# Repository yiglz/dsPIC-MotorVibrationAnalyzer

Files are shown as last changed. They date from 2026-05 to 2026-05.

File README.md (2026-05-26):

# dsPIC-MotorVibrationAnalyzer
Complete hardware and bare-metal firmware for real-time industrial motor vibration diagnostics using the dsPIC33F DSP engine.

Industrial motors vibrate in specific ways before they break down. This project acts as an early warning system. It is a custom-built embedded device that listens to motor vibrations, mathematically analyzes the frequencies in real-time, and points out mechanical issues before a failure happens.

Vibration_dsPIC33

**Used ICs:** dsPIC33FJ64MC204 (MCU), ADXL335 (Analog Accelerometer), MAX3232 (UART-RS232 Bridge), NCP716 & TLF50241ELV50 (Voltage Regulators).

This project does not use an operating system or HAL libraries. It is entirely written in bare-metal C.

To save energy, the system defaults to a deep hardware sleep mode. The operational workflow is executed as follows:

1. The user presses the physical **START BUTTON**. The processor wakes up and activates the status LED.
2. 10-second timer is started. During this time, ADC captures 4,000 samples of the vibration every single second.
3. To move data, DMA controller is used. The DMA continuously streams incoming data into a primary memory.
4. Once the first memory array is full, the DMA redirects data to a secondary array (Ping-Pong buffering). While the secondary array fills, the main processor executes FFT on the first one. Working in parallel ensures the system never misses a sample.
5. After 10 seconds, the device stops sampling. It averages the magnitudes and transmits a list of frequencies to a terminal via the RS232 port before returning to sleep.

This repository contains:
* **Firmware (`.c` & `.h` files):** Full bare-metal C source code, including register-level configurations for DMA, dual-channel ADC, Timers, UART, and the Complex FFT algorithms.
* **Schematic PDF:** The complete circuit diagram.
* **Gerber Files:** Production-ready PCB manufacturing files.

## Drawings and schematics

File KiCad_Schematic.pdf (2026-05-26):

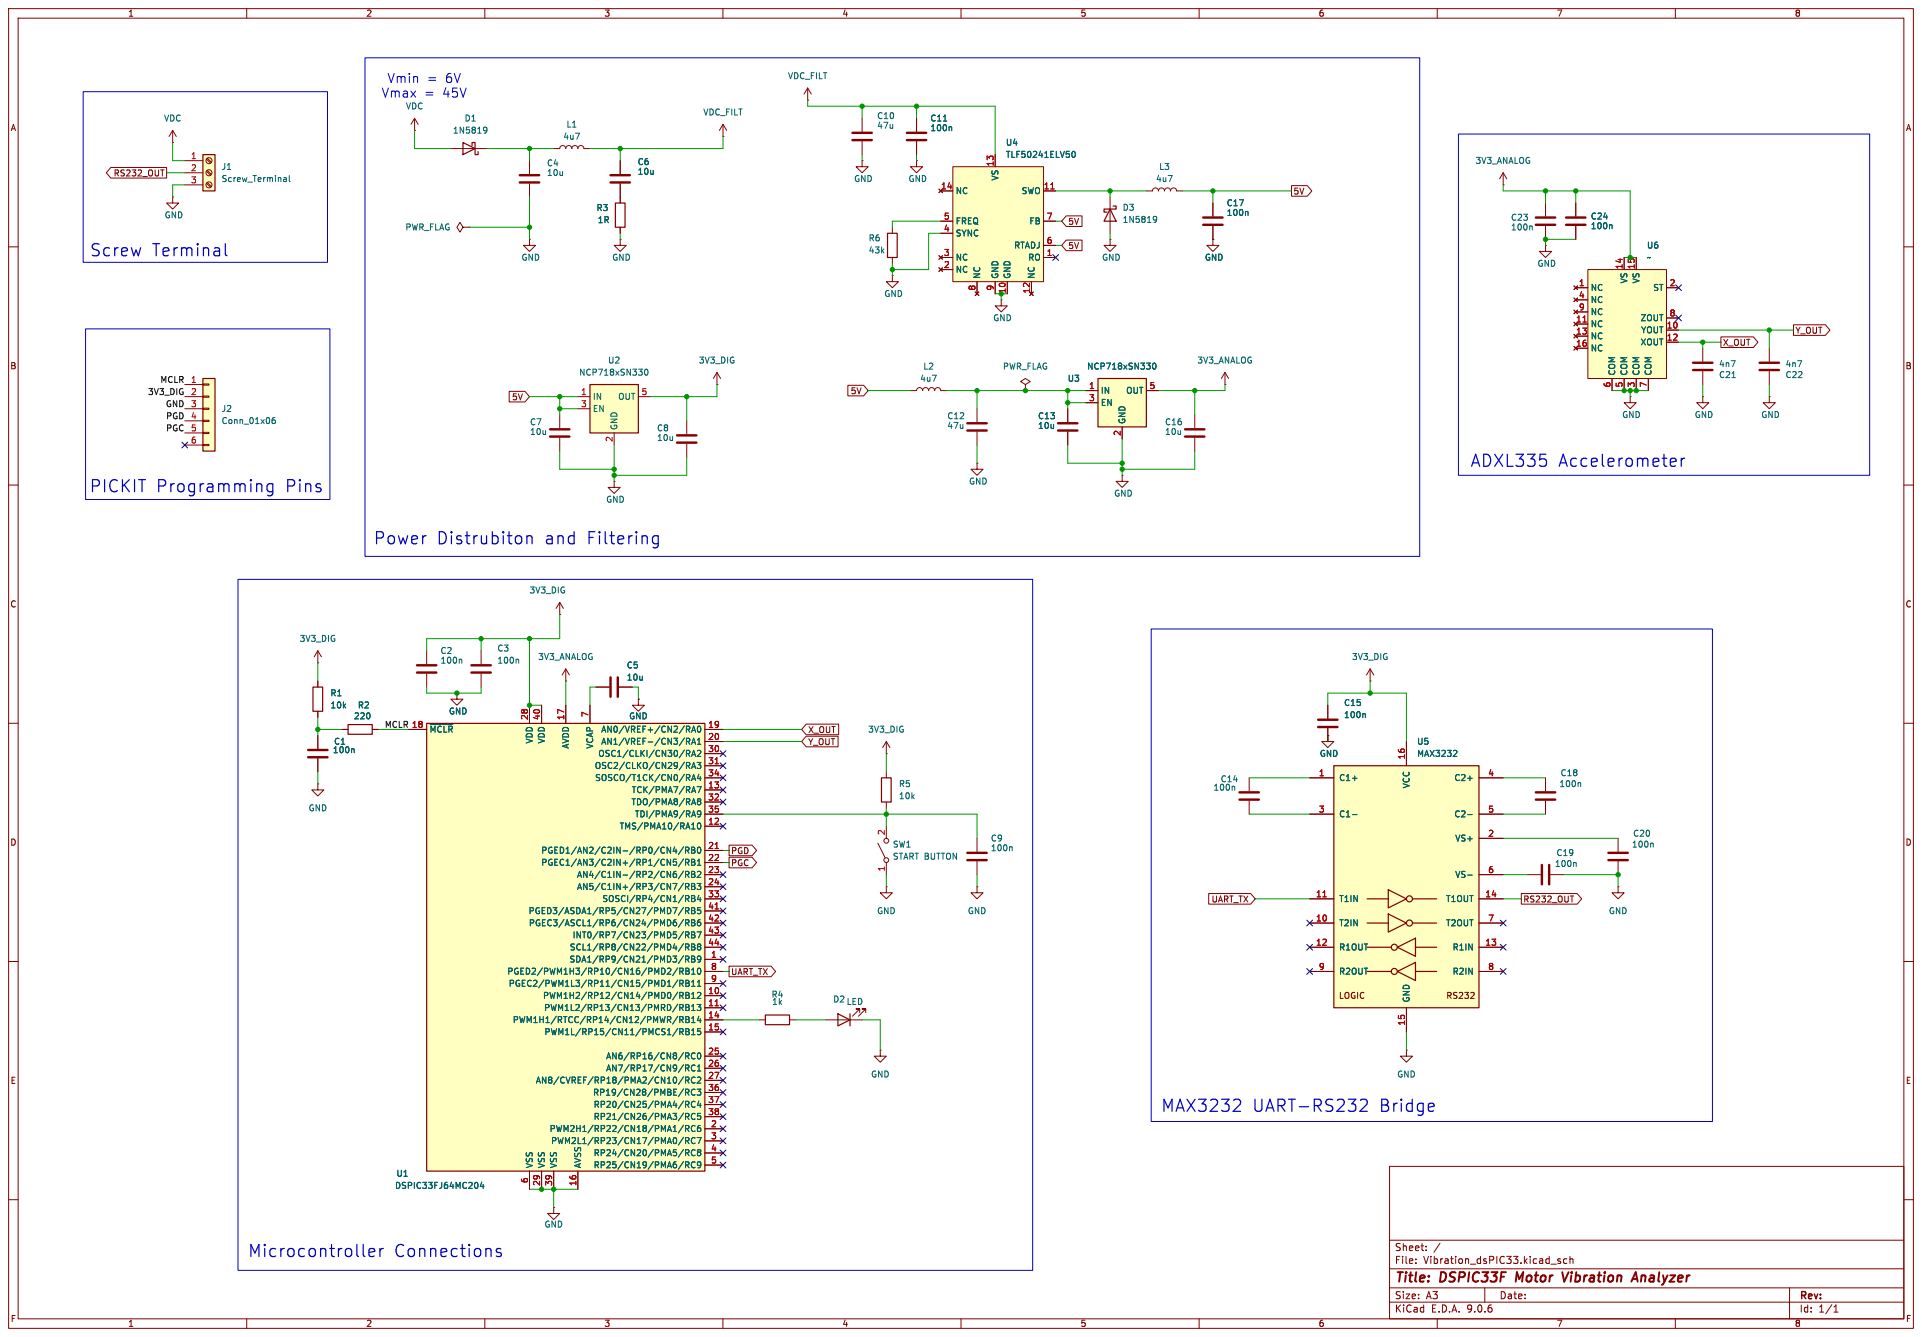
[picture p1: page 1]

9 GND 10 NC 12 SWO 11 FB 7 RTADJ 6 RO 1 C11

9 GND 10 NC 12 SWO 11 FB 7 RTADJ 6 RO 1 U4 TLF50241ELV50 GND GND

2 OUT 5 U2 NCP718xSN330 NC 14 FREQ 5 SYNC 4 NC 3 NC 2 NC

Power Distrubiton and Filtering

6 VDD 40 VSS 29 VSS 39 AVDD 17 AVSS 16 VCAP

7 AN0/VREF+/CN2/RA0 19 AN1/VREF-/CN3/RA1 20 OSC1/CLKI/CN30/RA2 30 OSC2/CLKO/CN29/RA3 31 SOSCO/T1CK/CN0/RA4 34 TCK/PMA7/RA7 13 TDO/PMA8/RA8 32 TDI/PMA9/RA9 35 TMS/PMA10/RA10 12 PGED1/AN2/C2IN-/RP0/CN4/RB0 21 PGEC1/AN3/C2IN+/RP1/CN5/RB1 22 AN4/C1IN-/RP2/CN6/RB2 23 AN5/C1IN+/RP3/CN7/RB3 24 SOSCI/RP4/CN1/RB4 33 PGED3/ASDA1/RP5/CN27/PMD7/RB5 41 PGEC3/ASCL1/RP6/CN24/PMD6/RB6 42

Id: 1/1 Title: DSPIC33F Motor Vibration Analyzer File: Vibration_dsPIC33.kicad_sch Sheet: /

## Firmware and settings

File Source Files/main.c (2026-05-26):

/*
 * File:   main.c
 * Author: Dev
 * Description: Main application for Motor Vibration Analyzer using dual-channel 
 * ADC, DMA Ping-Pong buffering, and in-place FFT calculation.
 */

// FBS (Boot Segment Configuration)
#pragma config BWRP = WRPROTECT_OFF     // Boot Segment Write Protect (Boot Segment may be written)
#pragma config BSS = NO_FLASH           // Boot Segment Program Flash Code Protection (No Boot program Flash segment)
#pragma config RBS = NO_RAM             // Boot Segment RAM Protection (No Boot RAM)

// FSS (Secure Segment Configuration)
#pragma config SWRP = WRPROTECT_OFF     // Secure Segment Program Write Protect (Secure segment may be written)
#pragma config SSS = NO_FLASH           // Secure Segment Program Flash Code Protection (No Secure Segment)
#pragma config RSS = NO_RAM             // Secure Segment Data RAM Protection (No Secure RAM)

// FGS (General Segment Configuration)
#pragma config GWRP = OFF               // General Code Segment Write Protect (User program memory is not write-protected)
#pragma config GSS = OFF                // General Segment Code Protection (User program memory is not code-protected)

// FOSCSEL (Oscillator Selection)
#pragma config FNOSC = FRCPLL           // Fast RC Oscillator with PLL (FRCPLL)
#pragma config IESO = ON                // Internal External Switch Over Mode enabled

// FOSC (Oscillator Configuration)
#pragma config POSCMD = NONE            // Primary Oscillator Disabled (Crystal-less operation)
#pragma config OSCIOFNC = OFF           // OSC2 pin has clock out function
#pragma config IOL1WAY = ON             // Peripheral Pin Select Configuration (Allow Only One Re-configuration)
#pragma config FCKSM = CSECMD           // Clock Switching Enabled, Clock Monitor Disabled

// FWDT (Watchdog Timer Configuration)
#pragma config WDTPOST = PS32768        // Watchdog Timer Postscaler (1:32,768)
#pragma config WDTPRE = PR128           // WDT Prescaler (1:128)
#pragma config WINDIS = OFF             // Watchdog Timer in Non-Window mode
#pragma config FWDTEN = OFF             // Watchdog timer explicitly disabled

// FPOR (Power-on Reset Configuration)
#pragma config FPWRT = PWR128           // POR Timer Value (128ms)
#pragma config ALTI2C = OFF             // I2C mapped to standard SDA1/SCL1 pins
#pragma config LPOL = ON                // PWM low side active-high
#pragma config HPOL = ON                // PWM high side active-high
#pragma config PWMPIN = ON              // PWM pins controlled by PORT register at Reset

// FICD (ICD Configuration)
#pragma config ICS = PGD1               // Communicate on PGC1/EMUC1 and PGD1/EMUD1
#pragma config JTAGEN = OFF             // JTAG is Disabled

#include <xc.h>
#include <dsp.h>
#include "DMA_ADC.h"
#include "TwiddleFactors.h"
#include "Timer.h"
#include "_10SecTimer.h"
#include "UART.h"


volatile unsigned long int XAccumulator[256] = {0};
volatile unsigned long int YAccumulator[256] = {0};
volatile unsigned int fftCount = 0;
volatile int ABufferFilterFlag = 0;
volatile int BBufferFilterFlag = 0;


fractcomplex XDataBuffer[256] __attribute__((space(ymemory), aligned(1024))) = {0};
fractcomplex YDataBuffer[256] __attribute__((space(ymemory), aligned(1024))) = {0};

volatile fractional XResultBuffer[256] = {0};
volatile fractional YResultBuffer[256] = {0};

void System_Pins_Init(void) {
    __builtin_write_OSCCONL(OSCCON & 0xBF); 
    RPOR7bits.RP14R = 3;  // Map UART1 TX to RP14 pin
    __builtin_write_OSCCONL(OSCCON | 0x40); // Lock Registers
}

void Button_Init(void){
    TRISB |= (1<<7);      // Set RB7 as input
    INTCON2 |= (1<<0);    // External Interrupt 0 on negative edge
    IFS0 &= ~(1<<0);      // Clear INT0 interrupt flag
    IEC0 |= (1<<0);       // Enable INT0 interrupt
}

// DMA
void __attribute__((interrupt, no_auto_psv)) _DMA0Interrupt(void){
    static char whichBuffer = 0;
    
    if(whichBuffer == 0){
        ABufferFilterFlag = 1;
    }
    else {
        BBufferFilterFlag = 1;
    }
    whichBuffer ^= 1;
    
    IFS0bits.DMA0IF = 0; // Clear DMA interrupt flag
}

void LED_Init(void){
    TRISC &= ~(1<<0); // Set RC0 as output (Status LED)
    LATC &= ~(1<<0);  // Turn off LED
}

// External Interrupt 0 ISR
void __attribute__((interrupt, no_auto_psv)) _INT0Interrupt(void){
    IFS0 &= ~(1<<0);  // Clear INT0 interrupt flag
}

void main(void) {
    // Oscillator Tuning for 40 MIPS
    PLLFBD = 41; 
    CLKDIV &= ~((1<<7) | (1<<6)); 
    CLKDIV &= ~((1<<4) | (1<<3) | (1<<2) | (1<<1) | (1<<0)); 
    
    // Initiate Clock Switch to FRCPLL
    __builtin_write_OSCCONH(0x01); 
    __builtin_write_OSCCONL(OSCCON | 0x01);
    
    // Wait for Clock and PLL to lock
    while ((OSCCON & ((1<<14) | (1<<13) | (1<<12))) != (1<<12)); 
    while (!(OSCCON & (1<<5)));
    
    //Initializations
    System_Pins_Init();
    ADC_AnalogPinSet();
    ADC_Init();
    DMA_ADC_Init();
    TimerInit();
    Timer_10Sec_Init();
    Button_Init();   
    UART_Init();
    LED_Init();
    
    while(1) { 
        int i, j, k;
        unsigned int avgX, avgY;

        //Enter low-power mode and wait for external trigger
        LATC &= ~(1<<0); 
        Sleep(); 
        LATC |= (1<<0);
        
        // 2. NEW MEASUREMENT
        fftCount = 0;
        for(k = 0; k <= 255; k++){
            XAccumulator[k] = 0;
            YAccumulator[k] = 0;
        }

        // Start Hardware Peripherals
        Timer_10Sec_Start();        
        ADC_Start();
        DMA_ADC_Start();
        TimerStart(); // Starts Timer3 for ADC triggering
 
        // Process data for the 10-second duration
        while (IFS1bits.T5IF != 1) {
            
            // Process Buffer A
            if (ABufferFilterFlag){
                for (i=0; i<=255; i++) {
                    XDataBuffer[i].real = BufferA[2*i];
                    XDataBuffer[i].imag = 0;
                    YDataBuffer[i].real = BufferA[2*i+1];
                    YDataBuffer[i].imag = 0;
                }
                ABufferFilterFlag = 0;
                
                //Complex FFT
                FFTComplexIP(8, &XDataBuffer[0], 
                            (fractcomplex*)__builtin_psvoffset(&twiddleFactors[0]),
                            __builtin_psvpage(&twiddleFactors[0]));
                FFTComplexIP(8, &YDataBuffer[0], 
                            (fractcomplex*)__builtin_psvoffset(&twiddleFactors[0]),
                            __builtin_psvpage(&twiddleFactors[0]));
                
                BitReverseComplex(8, &XDataBuffer[0]);
                BitReverseComplex(8, &YDataBuffer[0]);
                SquareMagnitudeCplx(256, &XDataBuffer[0], &XResultBuffer[0]);
                SquareMagnitudeCplx(256, &YDataBuffer[0], &YResultBuffer[0]);
                
                // Accumulate results for averaging
                for (k = 0; k <= 255; k++) {
                    XAccumulator[k] += XResultBuffer[k];
                    YAccumulator[k] += YResultBuffer[k];
                }
                fftCount++; 
            }
            
            // Process Buffer B
            if (BBufferFilterFlag){
                for (j=0; j<=255; j++) {
                    XDataBuffer[j].real = BufferB[2*j];
                    XDataBuffer[j].imag = 0;
                    YDataBuffer[j].real = BufferB[2*j+1];
                    YDataBuffer[j].imag = 0;
                }
                BBufferFilterFlag = 0;   
                
                FFTComplexIP(8, &XDataBuffer[0], 
                            (fractcomplex*)__builtin_psvoffset(&twiddleFactors[0]),
                            __builtin_psvpage(&twiddleFactors[0]));
                FFTComplexIP(8, &YDataBuffer[0], 
                            (fractcomplex*)__builtin_psvoffset(&twiddleFactors[0]),
                            __builtin_psvpage(&twiddleFactors[0]));
                
                BitReverseComplex(8, &XDataBuffer[0]);
                BitReverseComplex(8, &YDataBuffer[0]);
                SquareMagnitudeCplx(256, &XDataBuffer[0], &XResultBuffer[0]);
                SquareMagnitudeCplx(256, &YDataBuffer[0], &YResultBuffer[0]);
                        
                for (k = 0; k <= 255; k++) {
                    XAccumulator[k] += XResultBuffer[k];
                    YAccumulator[k] += YResultBuffer[k];
                }
                fftCount++; 
            }
        }
        
        //Stopping peripherals
        ADC_Stop();
        T3CON &= ~(1<<15);
        T4CON &= ~(1<<15);
        IFS1bits.T5IF = 0;
        
        /*STOP DMA
         */
        DMA0CON &= ~(1<<15);
        IEC0bits.DMA0IE = 0;
        IFS0bits.DMA0IF = 0;

        // Transmit FFT Data via UART
        UART_SendString("\r\n--- RESULTS ---\r\n");
        UART_SendString("Frequency_Index, X_Avg, Y_Avg \r\n");
        
        for(k = 0; k <= 255; k++){
            avgX = 0;
            avgY = 0;
            
            if (fftCount > 0) {
                avgX = (unsigned int)(XAccumulator[k] / fftCount);
                avgY = (unsigned int)(YAccumulator[k] / fftCount);
            }
            
            UART_SendInt(k);                 
            UART_SendString(", ");           
            
            // 4. Transmit the magnitudes
            UART_SendInt(avgX);  
            UART_SendString(", ");           
            
            UART_SendInt(avgY);  
            UART_SendString("\r\n");         
        }
        
        UART_SendString("--- PRESS THE BUTTON AGAIN FOR ANOTHER SESSION  ---\r\n");
    }
}

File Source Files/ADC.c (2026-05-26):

#include "ADC.h"

void ADC_AnalogPinSet(void){
    // Set RA0 and RA1 pins as input
    TRISA |= ((1<<1) | (1<<0));
    
    // AD1CHS0: Channel 0 Input Select
    // CH0SA = 0 (AN0 selected), CH0NA = 0 (Vref- selected)
    AD1CHS0 &= ~((1<<7) | (1<<4) | (1<<3) | (1<<2) | (1<<1));
    AD1CHS0 |= (1<<0);
    
    // AD1CHS123: Channel 1,2,3 Input Select
    AD1CHS123 &= ~((1<<2) | (1<<1) | (1<<0));
    
    // AD1PCFGL: Port Configuration Register 
    // Set AN0 and AN1 pins to Analog mode
    AD1PCFGL &= ~((1<<1) | (1<<0));
}

void ADC_Init(void){
    /* AD1CON1 Configuration:
     * Bit 12 (AD12B) : 1 = 12-bit, 1-channel ADC operation
     * Bit 9-8 (FORM) : 11 = Signed Fractional
     * Bit 6 (SSRC)   : 1 = Timer / PWM interval ends sampling and starts conversion
     * Bit 3 (SIMSAM) : 1 = Simultaneous sampling enabled
     * Bit 2 (ASAM)   : 1 = Auto-sampling enabled
     */
    AD1CON1 |= ((1<<12) | (1<<9) | (1<<8) | (1<<6) | (1<<3) | (1<<2));
    AD1CON1 &= ~((1<<13) | (1<<10) | (1<<7) | (1<<5)); 

    /* AD1CON2 Configuration:
     * Bit 8 (SMPI) : Interrupt rate selection
     * Other bits are cleared to default values
     */
    AD1CON2 |= (1<<8); 
    AD1CON2 &= ~((1<<15) | (1<<14) | (1<<13) | (1<<10) | (1<<9) | (1<<5) | (1<<4) | (1<<3) | (1<<2) | (1<<1) | (1<<0));

    /* AD1CON3 Configuration:
     * Auto-Sample Time bits (SAMC) and ADC Conversion Clock (ADCS) selection
     */
    AD1CON3 |= ((1<<5) | (1<<2) | (1<<1) | (1<<0)); 
    AD1CON3 &= ~((1<<15) | (1<<12) | (1<<11) | (1<<10) | (1<<9) | (1<<8) | (1<<7) | (1<<6) | (1<<4) | (1<<3));

    /* AD1CSSL: Input Scan Select Register
     */
    AD1CSSL |= ((1<<1) | (1<<0));
}

void ADC_Start(void){
    AD1CON1 |= (1<<15); // ADON = 1: Power up and enable the ADC module
}

void ADC_Stop(void){
    AD1CON1 &= ~(1<<15); // ADON = 0: Turn off the ADC module
}

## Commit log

2026-05-26 Gerber and drill files are added.
    [Vibration_dsPIC33-B_Cu.gbr, Vibration_dsPIC33-B_Mask.gbr, Vibration_dsPIC33-B_Paste.gbr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]
2026-05-26 Circuit schematic is added.
